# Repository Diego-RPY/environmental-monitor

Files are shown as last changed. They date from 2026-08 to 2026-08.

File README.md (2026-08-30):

# Project Name: Environmental Monitor
Developed an environmental monitor that reads a DHT11 sensor and displays the data on an lcd screen. Based on sensor's readings the system choses to activate the fans and decides whether to activate dehumidification, and enter either cooling mode, or stationary mode. I am currently developing the modular technology to deploy the device for different applications.

## Firmware Architecture


---

## Hardware Architecture
WARNING: Make sure all the components are tied to the STM32 ground.



---

## System Specifications

### Hardware
* **Main Controller:** STM32F401RE
* **Sensors:** DHT11, KY-040
* **Power:** 3.7V 3000mAh 103665 1S LiPo Battery, Micro JST 1.25mm 2-Pin, micro-USB to USB and plug into computer
* **Actuators & Fans:** 30 mm Fan 3.3V DC
* **Displays:** LCD 2004

### Software & Dependencies
* **Development Environment:** Arduino IDE (v2.3.10 recommended)
* **Board Manager:** STM 32 MCU based boards (v2.12.0) installed via the the Arduino Boards Manager

---

## Usage & Bringup

### Prerequisites
* Arduino IDE
* STM 32 Board Support Package (version 2.12.0) installed via the Arduino Boards Manager

### 1. Hardware Checklist
1. Connect the power source and ensure the LCD 2004 screen backlight turns on (blue screen light).
2. Manually connect the fan to the battery and check that the fan blades are spinning.
3. Connect the STM 32 board to the computer. Ensure the ARDUINO IDE recognizes the STM 32 board, and that the board's red LED turns on.

### 2. Execution
Note: This project leverages ARM Assembly (.S) for low-level performance.
1. Open your file manager and navigate to the /firmware/Final_Test_With_Treshold/ directory in this repository.
2. Double-click the main .ino file to launch it directly inside the Arduino IDE. (The IDE will automatically open the accompanying .S assembly tab next to it).
3. Navigate to the Tools > Board menu and select STM32F401RE
4. Select your exact board type and COM Port from the **Tools** menu.
5. Click the **Upload** arrow button in the top toolbar.

NOTE: In the docs folder the flowchart for all parts of the firmware is found, and in the electronics folder all the datasheets of the components used in the project are included. Both of these are pdfs and cannot be seen on github, in order to see them you will need to download them.

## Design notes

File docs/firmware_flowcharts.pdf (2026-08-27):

## 1 / 5 — Boot & Main Loop

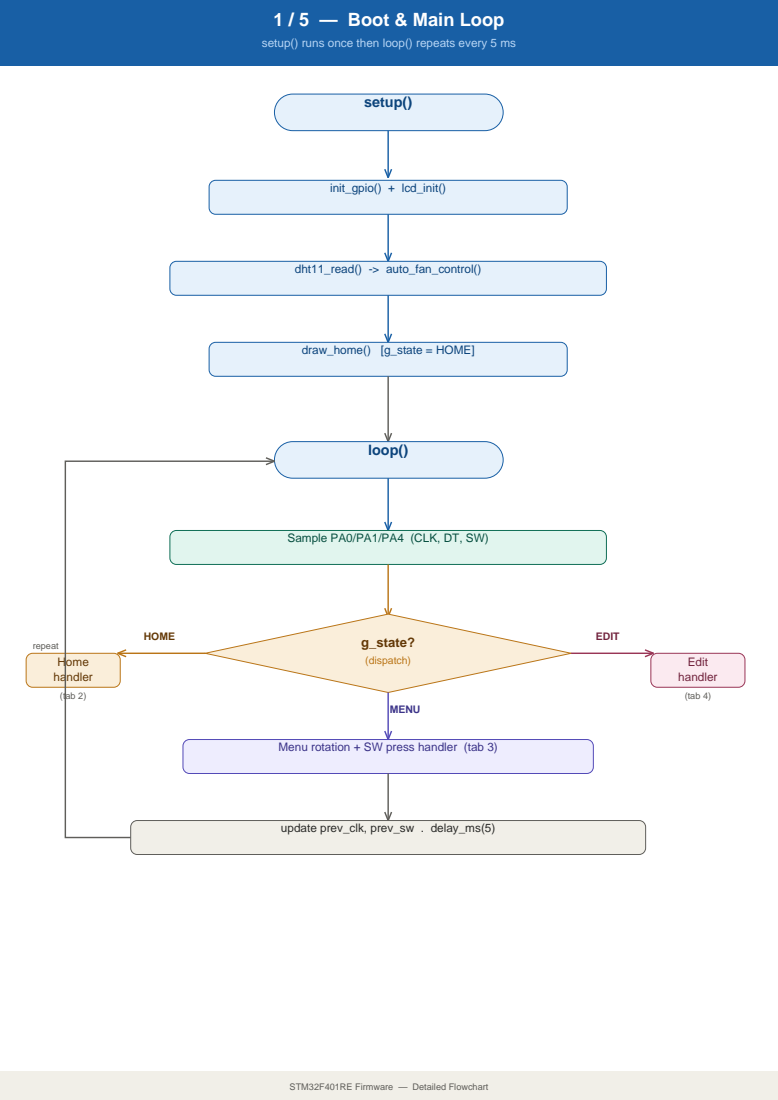
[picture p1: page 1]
setup(); init_gpio() + lcd_init(); dht11_read() -> auto_fan_control(); draw_home() [g_state = HOME]; loop(); g_state?; (dispatch); HOME; Home handler; (tab 2); EDIT; Edit handler; (tab 4); MENU; update prev_clk, prev_sw . delay_ms(5); repeat

setup() runs once then loop() repeats every 5 ms

Sample PA0/PA1/PA4 (CLK, DT, SW)

Menu rotation + SW press handler (tab 3)

STM32F401RE Firmware — Detailed Flowchart

## 2 / 5 — Home State Handler

SW push enters menu . 2-second timer reads DHT11

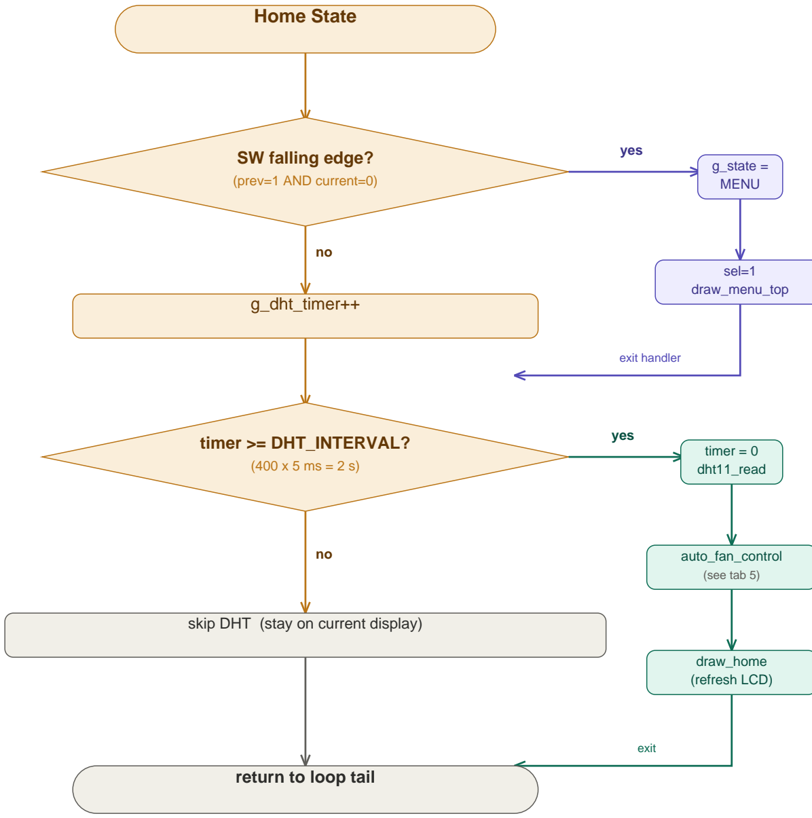
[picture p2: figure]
Home State; SW falling edge?; (prev=1 AND current=0); yes; g_state = MENU; sel=1 draw_menu_top; exit handler; g_dht_timer++; timer >= DHT_INTERVAL?; timer = 0 dht11_read; auto_fan_control (see tab 5); draw_home (refresh LCD); exit; skip DHT (stay on current display); return to loop tail

## 3 / 5 — Full Menu Navigation Tree

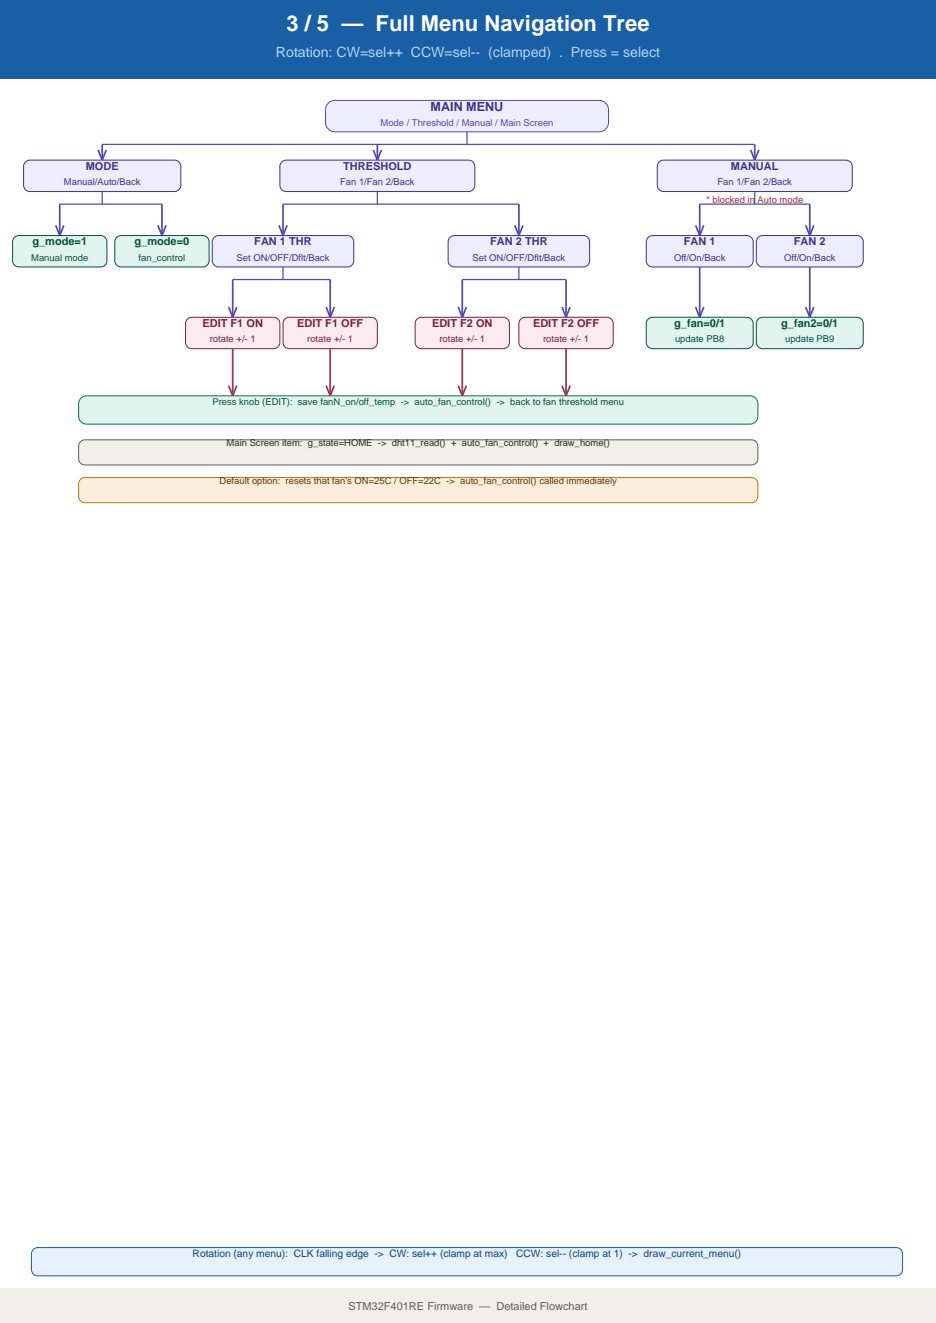
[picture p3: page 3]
MAIN MENU; g_mode=1; Manual mode; g_mode=0; fan_control; EDIT F1 ON; rotate +/- 1; EDIT F1 OFF; EDIT F2 ON; EDIT F2 OFF; g_fan=0/1; update PB8; g_fan2=0/1; update PB9

Rotation: CW=sel++ CCW=sel-- (clamped) . Press = select

Mode / Threshold / Manual / Main Screen

MODE
Manual/Auto/Back

THRESHOLD
Fan 1/Fan 2/Back

MANUAL
* blocked in Auto mode

FAN 1 THR
Set ON/OFF/Dflt/Back

FAN 2 THR

FAN 1
Off/On/Back

FAN 2

Press knob (EDIT): save fanN_on/off_temp -> auto_fan_control() -> back to fan threshold menu

Main Screen item: g_state=HOME -> dht11_read() + auto_fan_control() + draw_home()

Default option: resets that fan's ON=25C / OFF=22C -> auto_fan_control() called immediately

Rotation (any menu): CLK falling edge -> CW: sel++ (clamp at max) CCW: sel-- (clamp at 1) -> draw_current_menu()

## 4 / 5 — Threshold Edit State

EDIT_F1_ON / EDIT_F1_OFF / EDIT_F2_ON / EDIT_F2_OFF

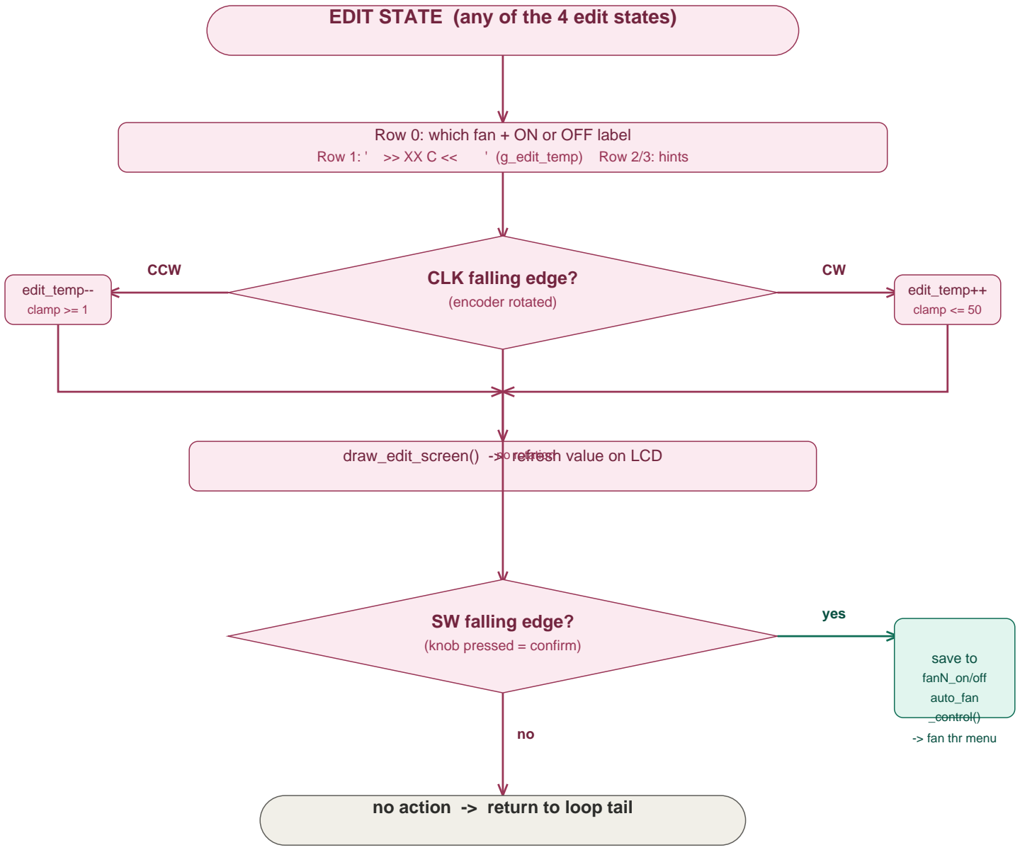
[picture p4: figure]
EDIT STATE (any of the 4 edit states); Row 0: which fan + ON or OFF label; CLK falling edge?; (encoder rotated); edit_temp++ clamp <= 50; CCW; edit_temp-- clamp >= 1; SW falling edge?; (knob pressed = confirm); yes; save to fanN_on/off auto_fan _control(); -> fan thr menu; no action -> return to loop tail

Row 1: ' >> XX C << | ' (g_edit_temp) Row 2/3: hints
draw_edit_screen() -> | refresh value on LCD no rotation

Valid range: 1 C (TEMP_MIN) to 50 C (TEMP_MAX) . each fan threshold set independently

## 5 / 5 — Auto Fan Control (auto_fan_control)

Called after every DHT read and when Auto mode is selected

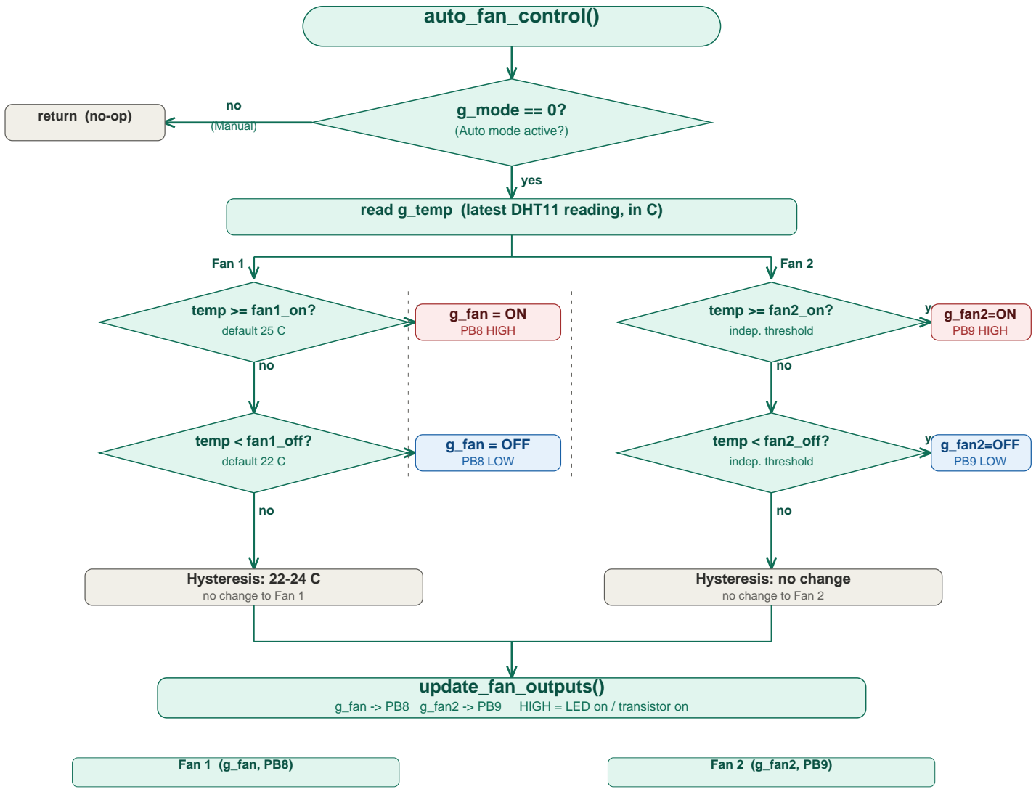
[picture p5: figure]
auto_fan_control(); g_mode == 0?; (Auto mode active?); (Manual); return (no-op); yes; Fan 1; Fan 2; temp >= fan1_on?; default 25 C; yes g_fan = ON; PB8 HIGH; temp < fan1_off?; default 22 C; yes g_fan = OFF; PB8 LOW; Hysteresis: 22-24 C no change to Fan 1; temp >= fan2_on?; indep. threshold; yesg_fan2=ON; PB9 HIGH; temp < fan2_off?; yesg_fan2=OFF; PB9 LOW; Hysteresis: no change no change to Fan 2; update_fan_outputs(); Fan 1 (g_fan, PB8); Fan 2 (g_fan2, PB9)

read g_temp (latest DHT11 reading, in C)

g_fan -> PB8 g_fan2 -> PB9 HIGH = LED on / transistor on

Hysteresis: fans only change state outside the dead zone to prevent rapid switching at the boundary Fan 1 and Fan 2 each have independent ON and OFF thresholds set in the Threshold menu (see tab 3)

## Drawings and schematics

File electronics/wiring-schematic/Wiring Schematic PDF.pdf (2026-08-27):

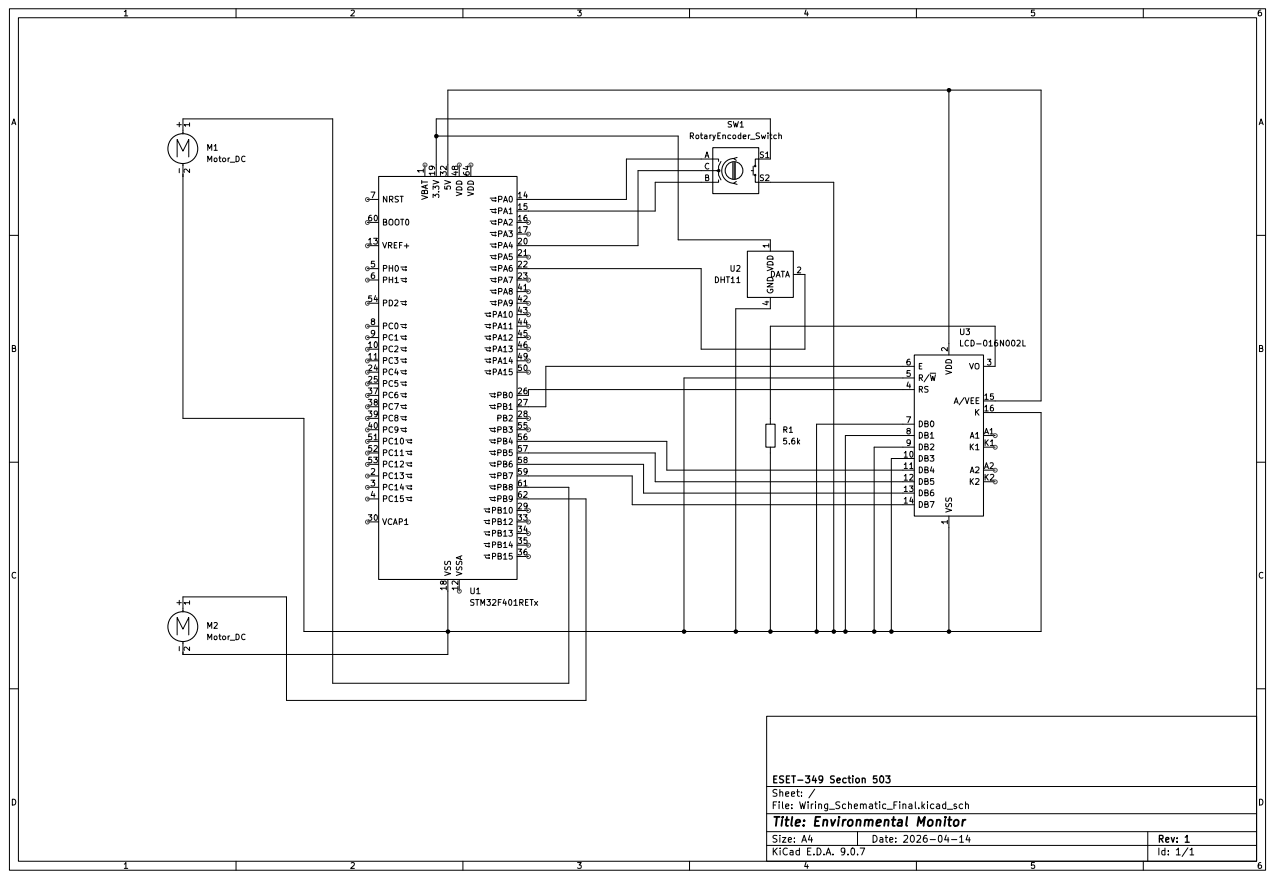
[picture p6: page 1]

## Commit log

2026-08-27 Update README with fan details and wiring diagram
    Added fan specification and wiring diagram with pin mapping.
2026-08-27 Revise README with updated specs and usage instructions
    Updated sensor and hardware specifications, added firmware and hardware architecture sections, and revised usage instructions.
2026-08-30 Add note on firmware flowchart and datasheets
    Added note about documentation and datasheets availability.
